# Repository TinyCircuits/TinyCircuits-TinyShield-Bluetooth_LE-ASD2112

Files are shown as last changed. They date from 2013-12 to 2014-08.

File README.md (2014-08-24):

# TinyCircuits TinyShield Bluetooth LE Board
# ASD2112 Rev2

These are the design files for the TinyCircuits ASD2112 Rev 2 PCB.  This is a TinyShield board that has a Bluegiga BLE112 Bluetooth Low Energy (or Smart) 4.0 module, local power supply and level shifters to connect between the TinyDuino and the Bluetooth LE Module. 

Format is in Cadsoft Eagle format - Eagle version 6.2 was used for the original design.

For more infomation on this, check out the product page at Tiny-Circuits.com:  https://tiny-circuits.com/tiny-shield-bluetooth-low-energy.html

#License:

Design by TinyCircuits.
All design files are released under the Creative Commons Attribution Share-Alike 3.0 License, see the following link for details: http://creativecommons.org/licenses/by-sa/3.0

All text above must be included in any redistribution or derived design

This project uses designs and concepts developed as part of the Arduino project and the LilyPad project.  The TinyCircuits design files themselves (schematics, PCB and libraries) are not directly derived from these works' design files and have been created new, however the concepts and basic architecture behind the TinyDuino and TinyLily products are derived and we thank the hard work of the organizations below for their contributions to open-source hardware:
  
Original Arduino Uno Design by Team Arduino

LilyPad Arduino Design by Leah Buechley and Sparkfun Electronics

Please support the open-source hardware community

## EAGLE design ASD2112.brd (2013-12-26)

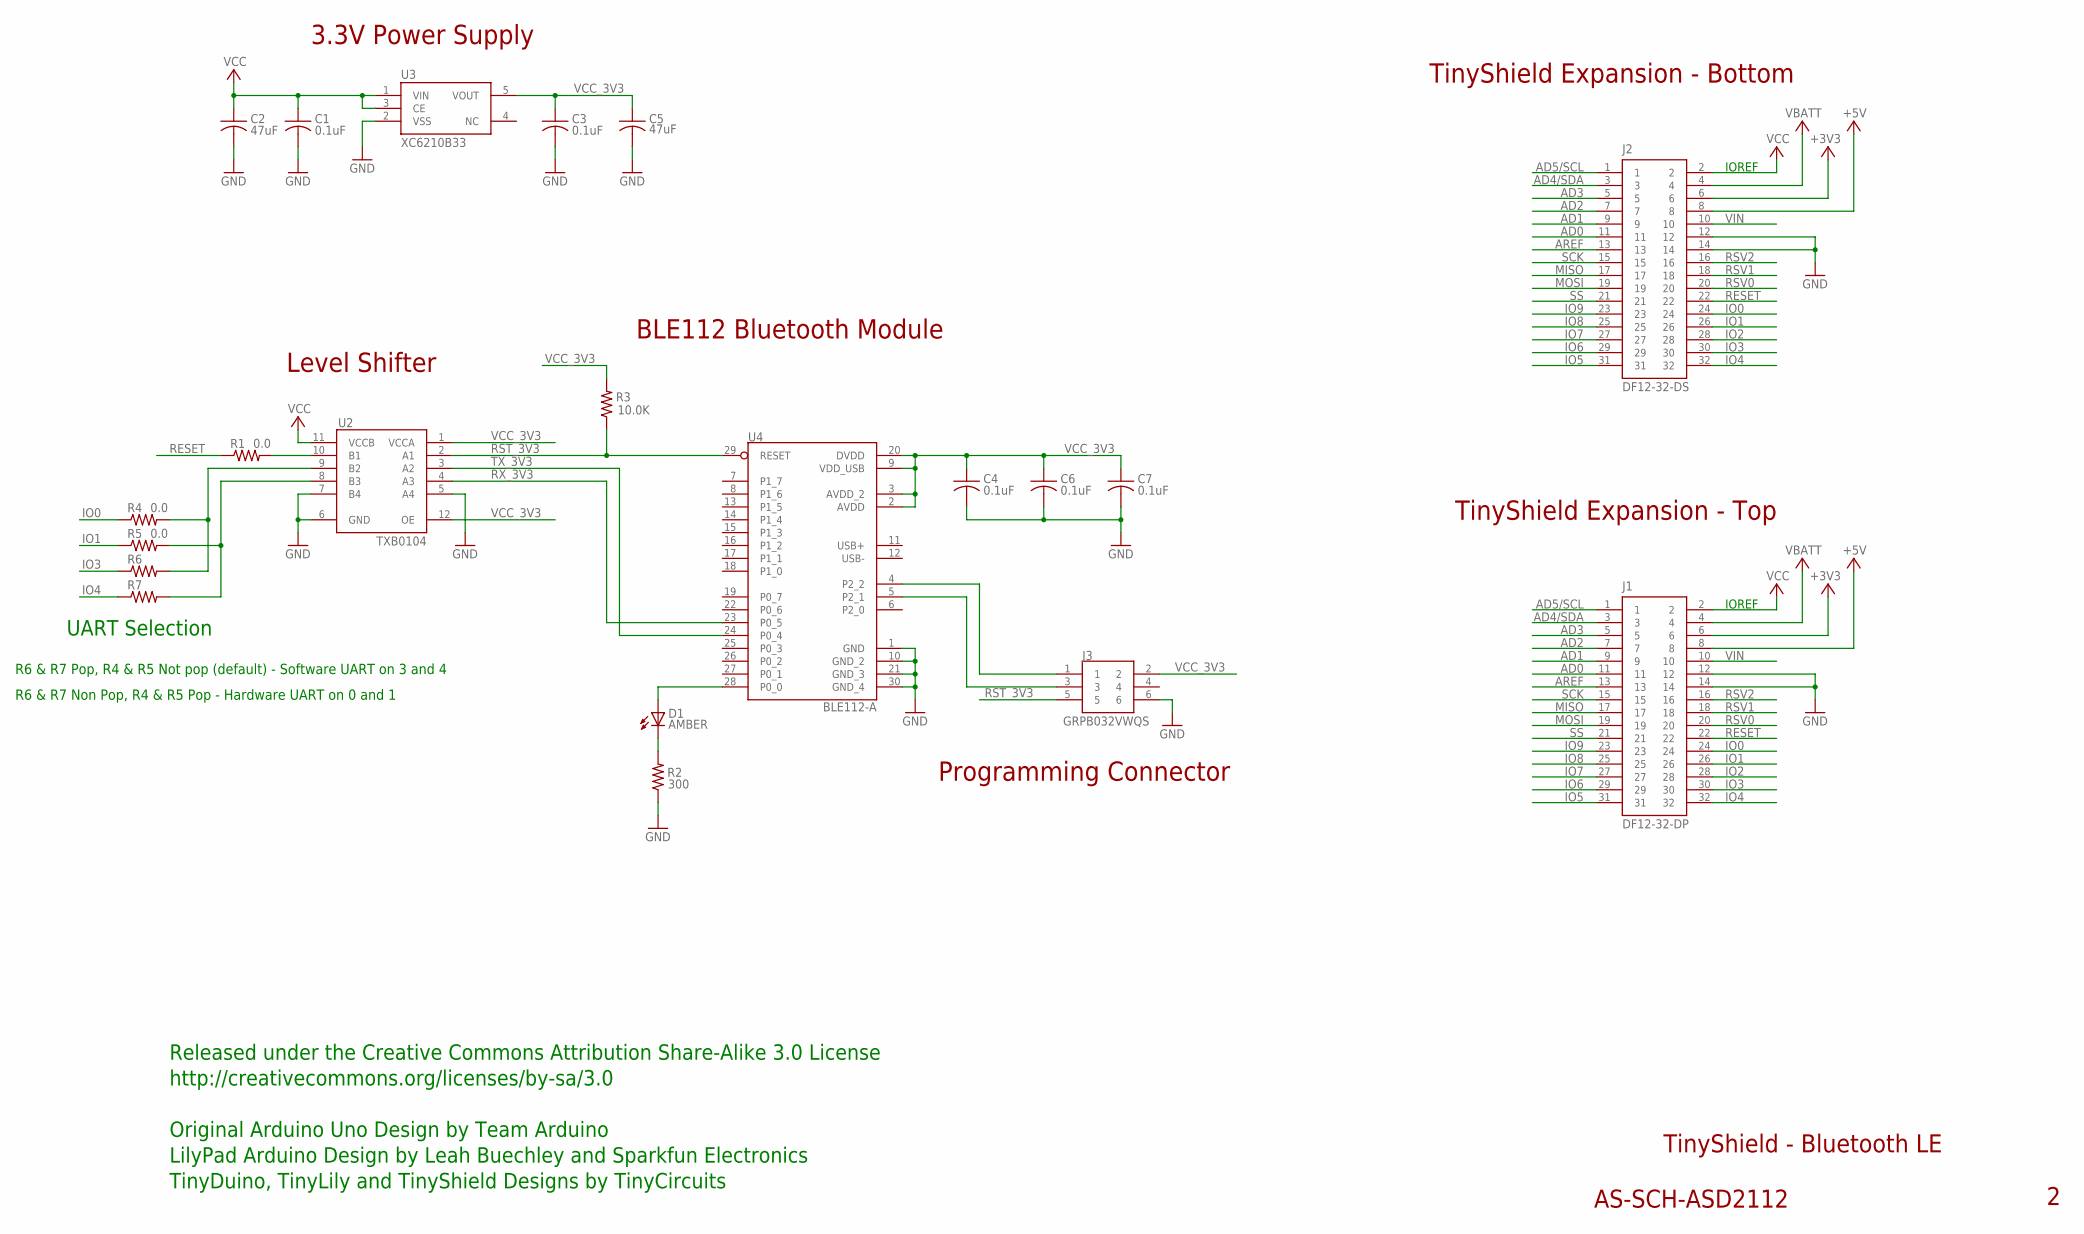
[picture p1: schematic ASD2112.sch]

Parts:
C1, C3, C4, C6, C7: 0.1uF; C0402; PARTNO AS-ITM-00008
C2: 47uF; C1206; PARTNUM AS-ITM-00049
C5: 47uF; C1206
D1: AMBER; LNJ_LED
J1: DF12-32-DP; PARTNO AS-ITM-00015
J2: DF12-32-DS; PARTNO AS-ITM-00012
J3: GRPB032VWQS; 2X3_.05"_SMT_HEADER
R1: 0.0; 0402
R2: 300; 0402; PARTNO AS-ITM-00016
R3: 10.0K; 0402
R4, R5: 0.0; 0402; PARTNO AS-ITM-00076
R6, R7: 0.0; 0402_SHORT
U2: TXB0104; UQFN-12
U3: XC6210B33; SOT-25
U4: BLE112-A; BLUEGIGA_BLE_MODULE

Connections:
+3V3: J1.6, J2.6
+5V: J1.8, J2.8
AD0: J1.11, J2.11
AD1: J1.9, J2.9
AD2: J1.7, J2.7
AD3: J1.5, J2.5
AD4/SDA: J1.3, J2.3
AD5/SCL: J1.1, J2.1
AREF: J1.13, J2.13
GND: C1.2, C2.2, C3.2, C4.2, C5.2, C6.2, C7.2, J1.12, J1.14, J2.12, J2.14, J3.6, R2.1, U2.5 (A4), U2.6 (GND), U2.7 (B4), U3.2 (VSS), U4.1 (GND), U4.10 (GND_2), U4.21 (GND_3), U4.30 (GND_4)
IO0: J1.24, J2.24, R4.1
IO1: J1.26, J2.26, R5.1
IO2: J1.28, J2.28
IO3: J1.30, J2.30, R6.1
IO4: J1.32, J2.32, R7.1
IO5: J1.31, J2.31
IO6: J1.29, J2.29
IO7: J1.27, J2.27
IO8: J1.25, J2.25
IO9: J1.23, J2.23
MISO: J1.17, J2.17
MOSI: J1.19, J2.19
unnamed: D1.A, U4.28 (P0_0)
unnamed: R4.2, R6.2, U2.9 (B2)
unnamed: R5.2, R7.2, U2.8 (B3)
unnamed: J3.3, U4.5 (P2_1)
unnamed: R1.2, U2.10 (B1)
unnamed: J3.1, U4.4 (P2_2)
unnamed: D1.C, R2.2
RESET: J1.22, J2.22, R1.1
RST_3V3: J3.5, R3.1, U2.2 (A1), U4.29 (RESET)
RSV0: J1.20, J2.20
RSV1: J1.18, J2.18
RSV2: J1.16, J2.16
RX_3V3: U2.4 (A3), U4.23 (P0_5)
SCK: J1.15, J2.15
SS: J1.21, J2.21
TX_3V3: U2.3 (A2), U4.24 (P0_4)
VBATT: J1.4, J2.4
VCC: C1.1, C2.1, J1.2, J2.2, U2.11 (VCCB), U3.1 (VIN), U3.3 (CE)
VCC_3V3: C3.1, C4.1, C5.1, C6.1, C7.1, J3.2, R3.2, U2.1 (VCCA), U2.12 (OE), U3.5 (VOUT), U4.2 (AVDD), U4.3 (AVDD_2), U4.9 (VDD_USB), U4.20 (DVDD)
VIN: J1.10, J2.10

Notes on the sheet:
TinyShield Expansion - Bottom
TinyShield - Bluetooth LE
AS-SCH-ASD2112
TinyShield Expansion - Top
IOREF
Released under the Creative Commons Attribution Share-Alike 3.0 License
http://creativecommons.org/licenses/by-sa/3.0
LilyPad Arduino Design by Leah Buechley and Sparkfun Electronics
TinyDuino, TinyLily and TinyShield Designs by TinyCircuits
Original Arduino Uno Design by Team Arduino
3.3V Power Supply
BLE112 Bluetooth Module
Level Shifter
Programming Connector
UART Selection
R6 & R7 Pop, R4 & R5 Not pop (default) - Software UART on 3 and 4
R6 & R7 Non Pop, R4 & R5 Pop - Hardware UART on 0 and 1

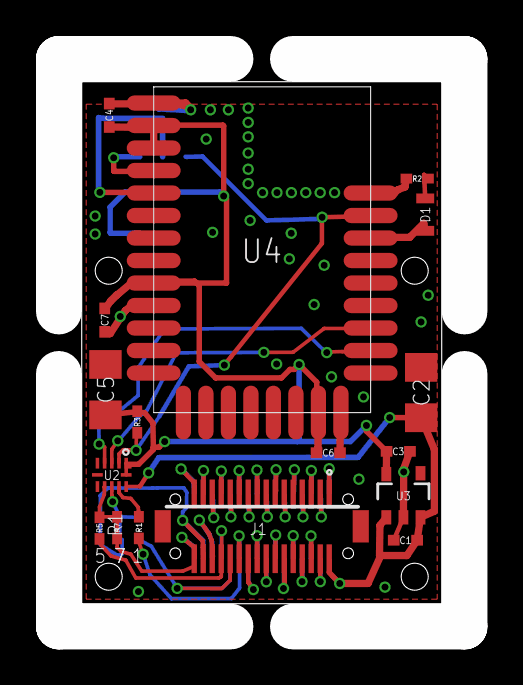
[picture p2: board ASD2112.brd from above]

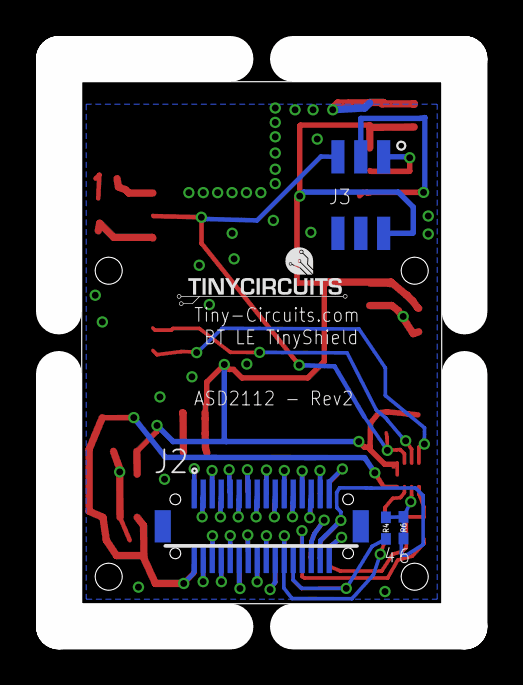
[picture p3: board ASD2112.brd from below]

Board: 2 copper layers, 20.0 x 29.0 mm, 22 parts (4 on the bottom side), 42 nets.

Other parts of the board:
U$1: DOCFIELD-TINYCIRCUITS-PCB
